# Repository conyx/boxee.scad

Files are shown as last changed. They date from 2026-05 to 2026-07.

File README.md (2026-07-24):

boxee.scad
==========

Parametric storage box with lid, created in [OpenSCAD](https://openscad.org/).
Everything is configured from the Customizer — no code editing needed.

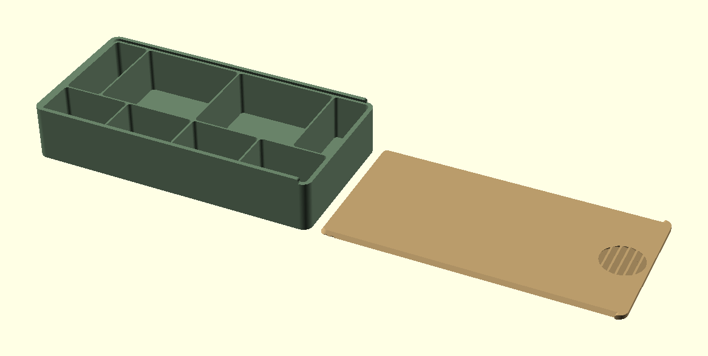
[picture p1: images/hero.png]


Main features
-------------

- [Compartment layout](#compartments) defined by a simple text string
- 10 [lid types](#lid-types) — friction lip, magnets, latches, hinges, slider
  and their combinations
- [Hinges](#hinges) joined by snap-fit (no hardware), pin, screw with nut or
  self-tapping screw
- [Snap locks](#snap-locks) holding the slider lid and latches closed
- [Magnet closure](#magnets--pausing-the-print) with print-pause support
- Corner [rounding](#rounding), [lid notches](#lid-notches),
  [connection bump/groove](#connection-groove--bump-mini-lip) (mini lip)
- [Dimension summary and hardware "shopping list"](#usage) (screws, pins,
  magnets)

Dependencies
------------

- **OpenSCAD — a recent [development snapshot (nightly)](https://openscad.org/downloads.html#snapshots) is recommended.**
  The 2021.01 stable release works too, but can be very slow with some specific
  parameters.
- **[BOSL2 library](https://github.com/BelfrySCAD/BOSL2)** — use the latest master;
  the hinges rely on recent BOSL2 features. Install it into your OpenSCAD library
  folder as described in the [BOSL2 installation guide](https://github.com/BelfrySCAD/BOSL2?tab=readme-ov-file#installation)
  (find the folder via *File ▸ Show Library Folder* in OpenSCAD).

Usage
-----

1. Open `main.scad` in OpenSCAD and show the Customizer (*Window ▸ Customizer*).
2. Define compartments and pick a lid type (see below). Every parameter has a
   description in the Customizer.
3. Preview (F5), render (F6), export STL. All parts are laid out side by side in
   print orientation.

The console (and a summary plate under the model in preview) reports the outside
dimensions, the hardware you need (screws, pins, magnets) and print-pause heights
for magnet closures.

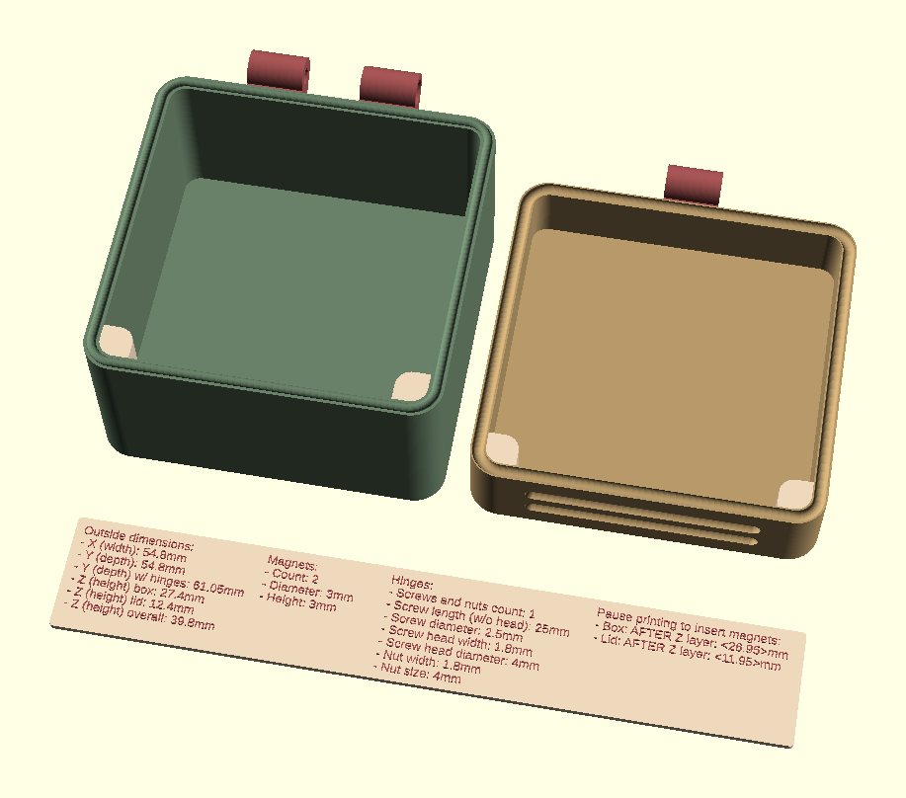
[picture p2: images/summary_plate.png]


Examples
--------

The [examples](examples) folder contains three ready-to-print projects, each
with the STL and photos of the printed result:

- **[Medi box](examples/medi_box)** — medical box with a slider lid and
  compartments sized for pill bottles; the cross-shaped notches on the lid make
  opening easier (the healthcare symbol visible on the walls in the photo is a
  negative volume added in the slicer software).
- **[Hardware box](examples/hardware_box)** — organizer for small screws and
  nuts, hinged together and lockable by a latch with snap lock. Needs two
  2.5 × 30 mm screws with nuts for the hinges.
- **[Tool box](examples/tool_box)** — box for iFixit tools with a lip and
  magnetic lid (the screwdriver pattern visible on the lid in the photo was
  added in the slicer software). Needs four 4 × 4 mm cylindrical magnets.

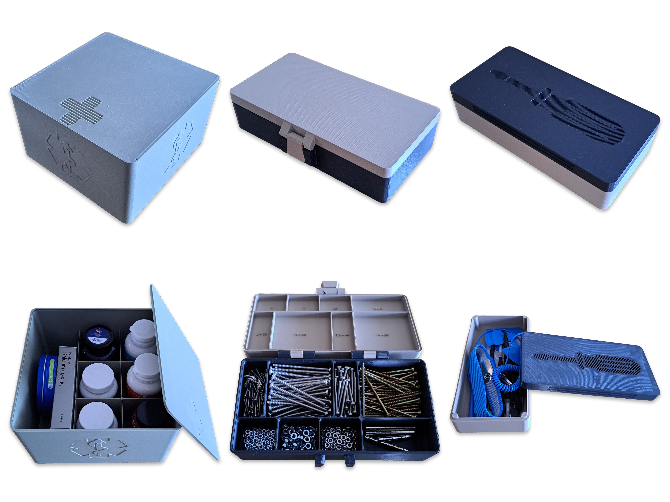
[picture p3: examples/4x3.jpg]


Compartments
------------

Compartments are defined by the text parameter `compartments_dimensions`.
Each row is `DEPTH, WIDTH, WIDTH, ...` — the first number is the row depth (Y),
followed by the widths (X) of its compartments. Rows are separated by `;`.
The box size is derived from the compartments plus wall/separator thickness —
`"50, 50"` gives a single 50×50 mm compartment.

`"50, 20, 55, 55, 20; 25, 37.5, 37.5, 37.5, 37.5"` — two rows: a 50 mm deep row
with four compartments and a 25 mm deep row with four equal ones.

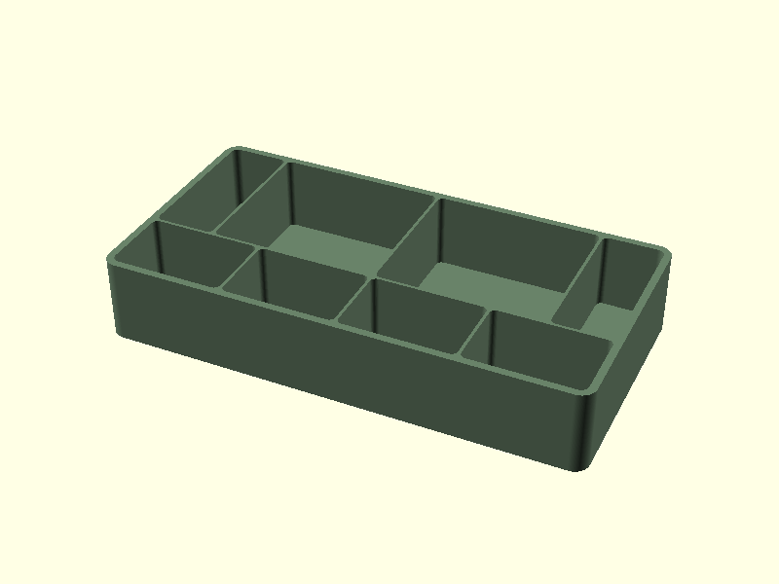
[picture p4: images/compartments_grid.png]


`compartments_transpose = true` — same definition, rows run along X instead of Y.

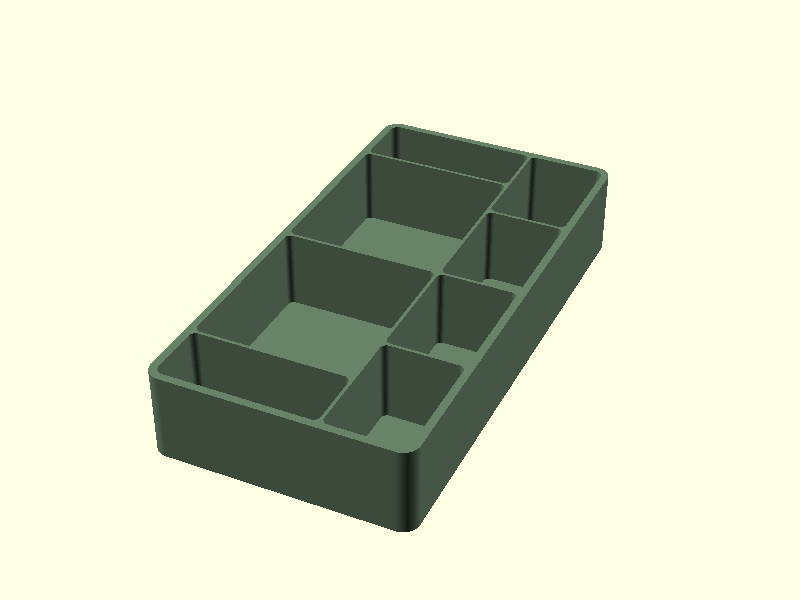
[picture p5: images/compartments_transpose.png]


`separators_z_offset = 15` — separators lowered from the top, leaving shared
space above the compartments.

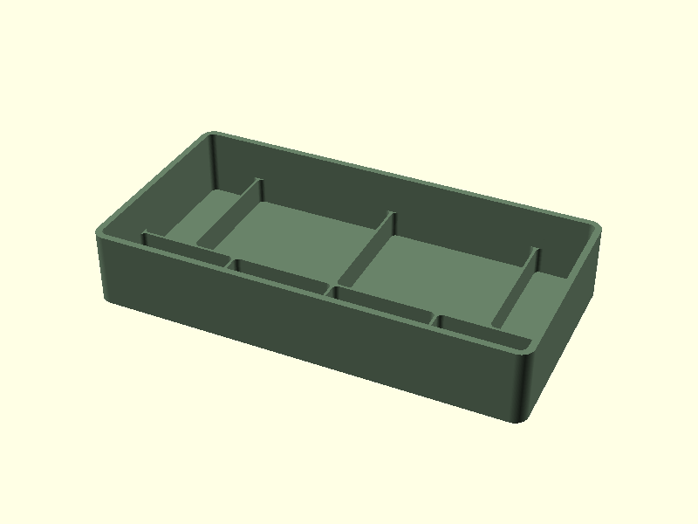
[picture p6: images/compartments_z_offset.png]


`separators_inside_lid = true` — matching separators are also generated inside
the lid (any lid type except slider).

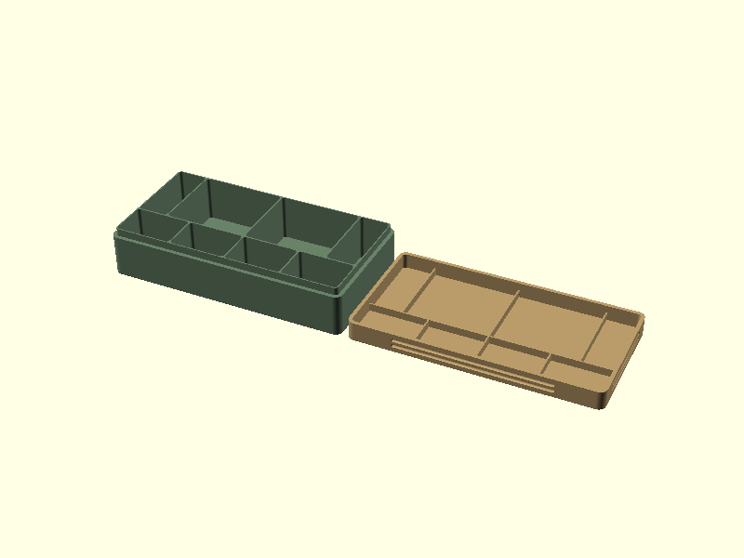
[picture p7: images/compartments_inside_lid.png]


Lid types
---------

Selected by `lid_type`. Box is always printed as one part; the lid (and latches)
are separate parts laid out next to it.

**No lid** (`no_lid`) — open tray.

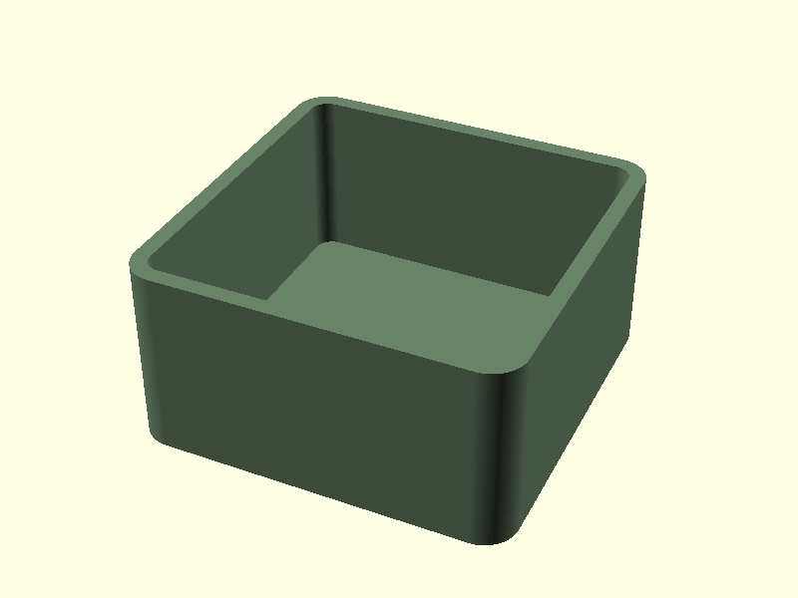
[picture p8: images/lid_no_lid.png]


**Lip** (`lip`) — inner lip on the box, the lid holds by friction. Tune the fit
with `lip_tolerance` (lower = tighter).

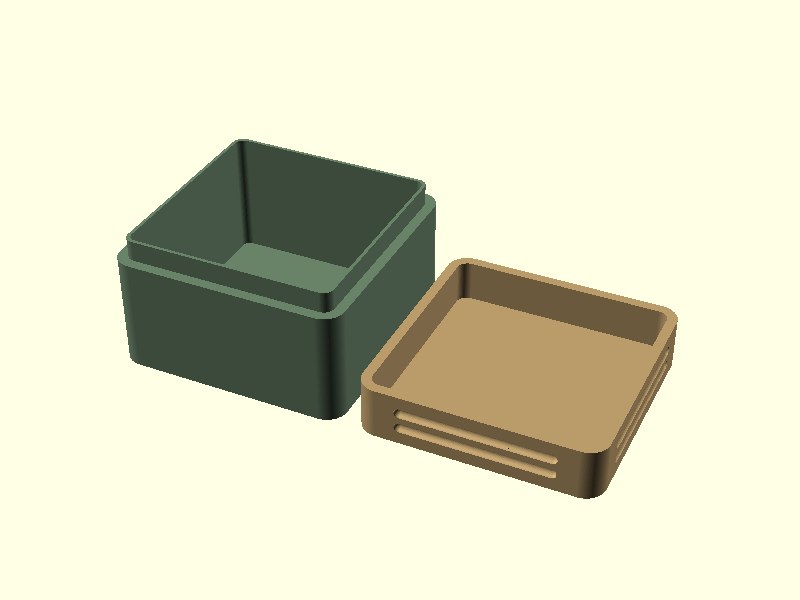
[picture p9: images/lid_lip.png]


**Magnets** (`magnets`) — flat mating faces with 2 or 4 magnet pairs in corner
holders. See [Magnets](#magnets--pausing-the-print).

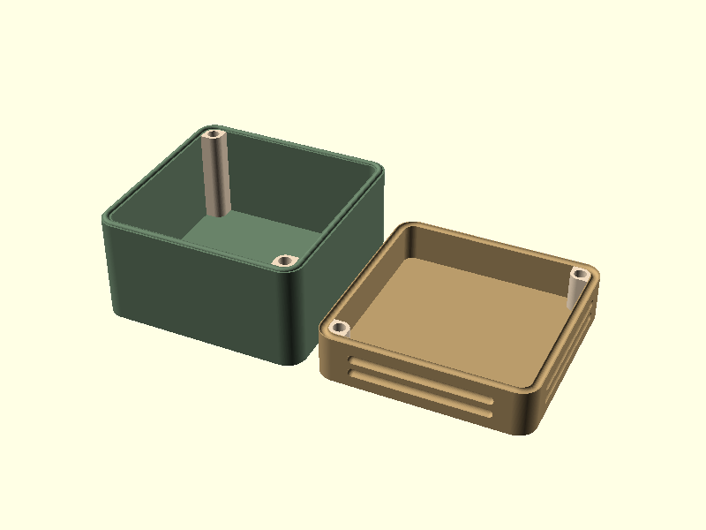
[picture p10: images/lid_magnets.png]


**Lip and magnets** (`lip_magnets`) — lip aligns the lid, magnets hold it closed.

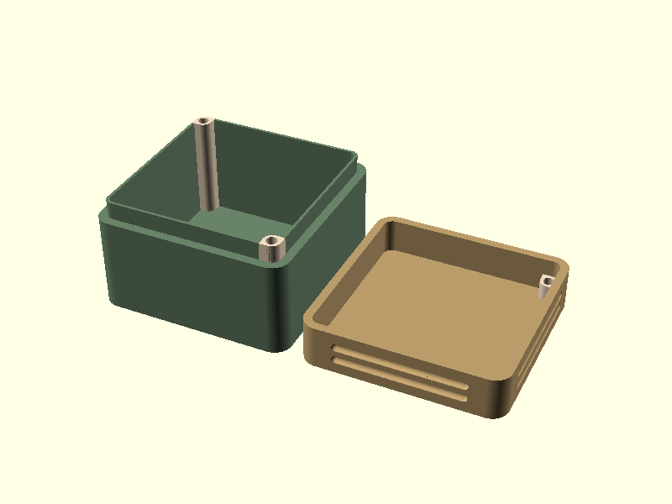
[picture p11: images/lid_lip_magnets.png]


**Latches** (`latches`) — dovetail latches on the front and back. The latch
swings on a snap-fit hinge and clicks onto the box.

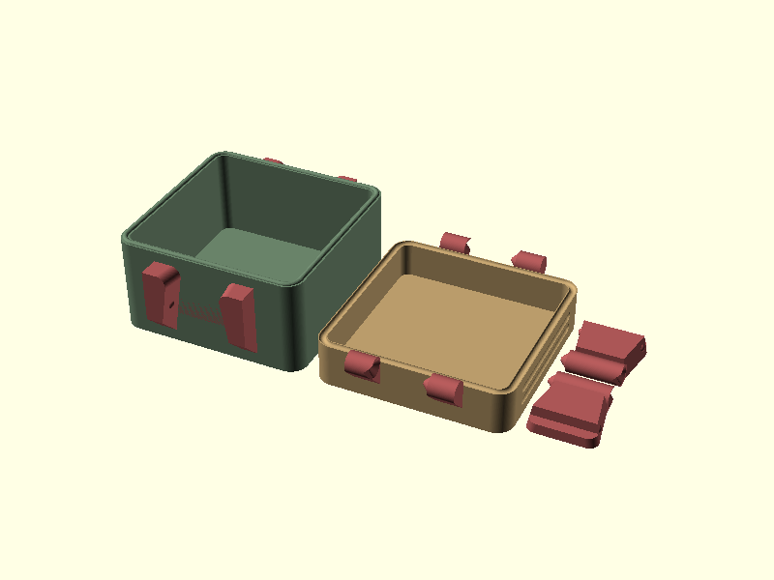
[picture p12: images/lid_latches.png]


**Lip and latches** (`lip_latches`) — friction lip plus latches.

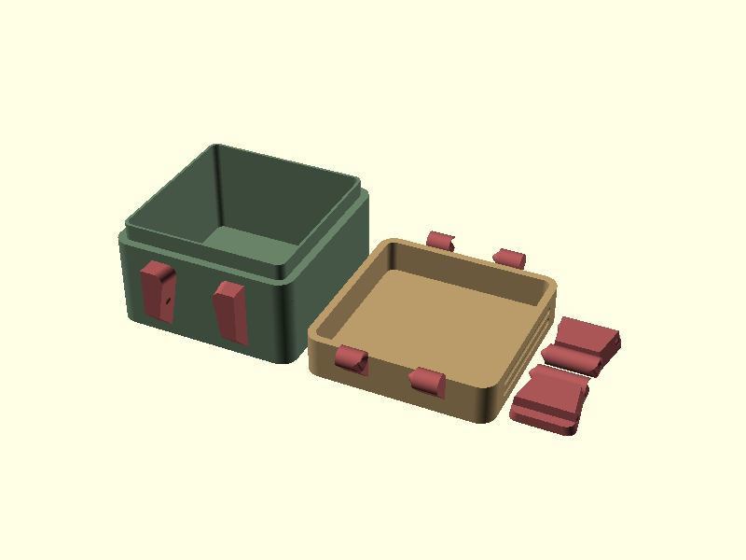
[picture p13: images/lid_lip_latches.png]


**Hinges** (`hinges`) — lid hinged at the back, nothing holds the front closed.

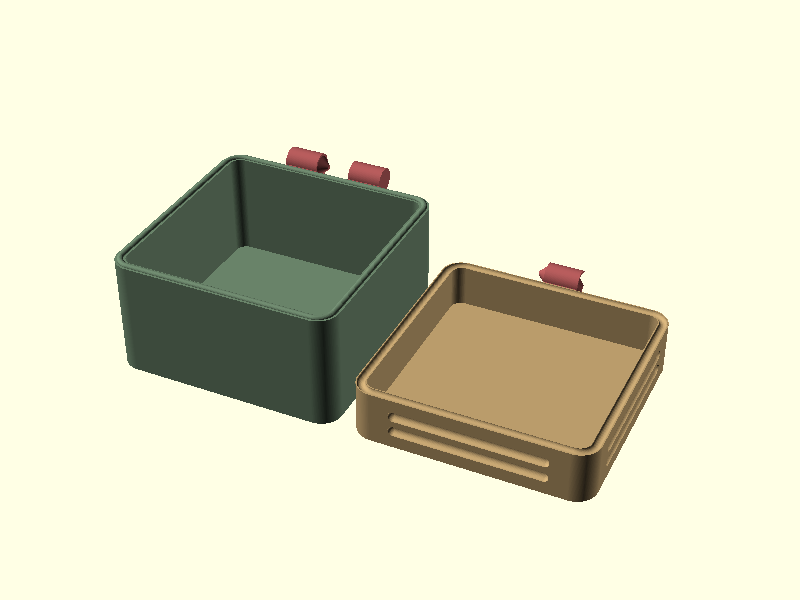
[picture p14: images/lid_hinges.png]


**Hinges and magnets** (`hinges_magnets`) — hinged lid held closed by magnets
(with 2 magnets both sit at the front edge).

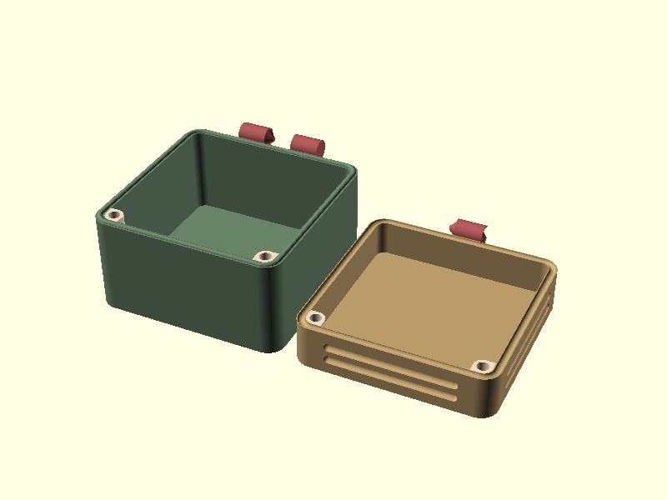
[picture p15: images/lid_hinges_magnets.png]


**Hinges and latches** (`hinges_latches`) — hinged lid with latches at the
front only.

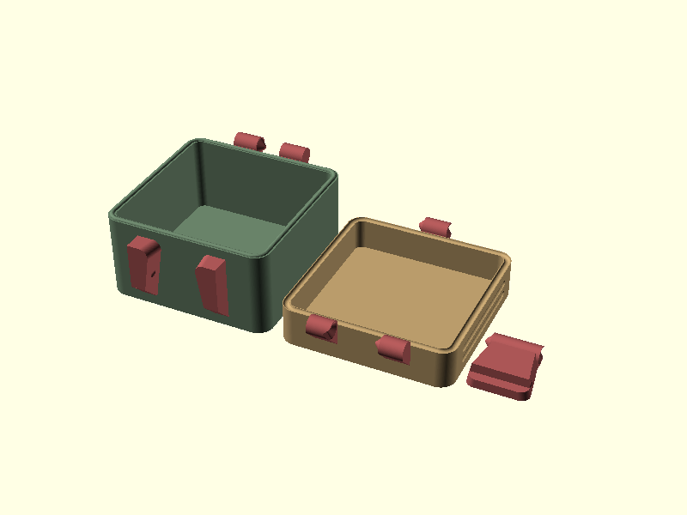
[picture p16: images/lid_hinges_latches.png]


**Slider** (`slider`) — flat lid slides into side rails, with optional snap lock
and a notch pattern for grip.

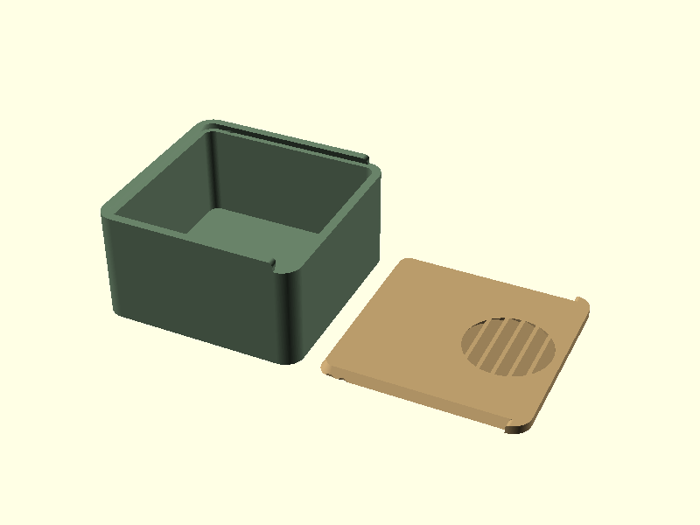
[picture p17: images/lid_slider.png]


Hinges
------

`hinge_join_type` selects how the hinge halves (one printed on the box, one on
the lid) are joined.

**Snap-fit** (`snap_fit`) — no hardware. Built-in cones on one half click into
sockets on the other; assembled by pressing together after printing. Needs ≥ 3
segments.

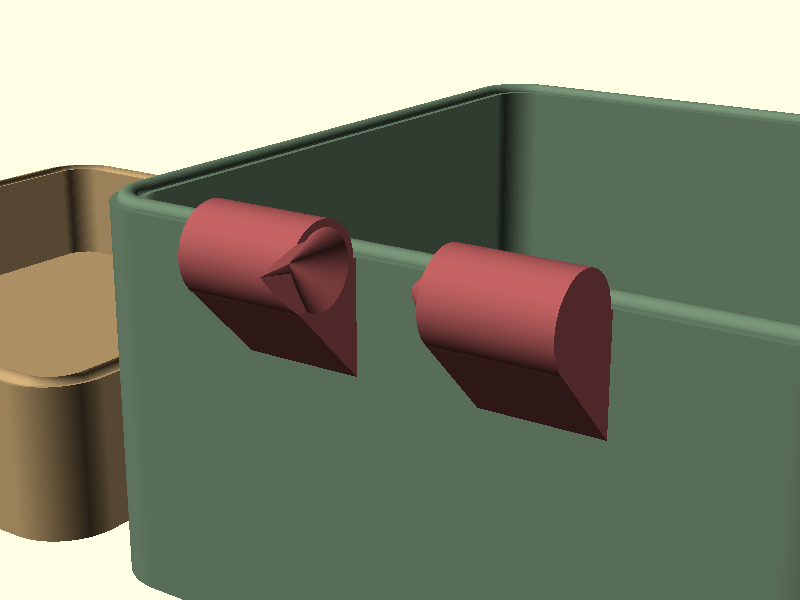
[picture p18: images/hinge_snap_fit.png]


**Simple pin** (`pin`) — plain hole through the knuckles. Use a nail, rod or a
piece of 1.75 mm filament as the pin.

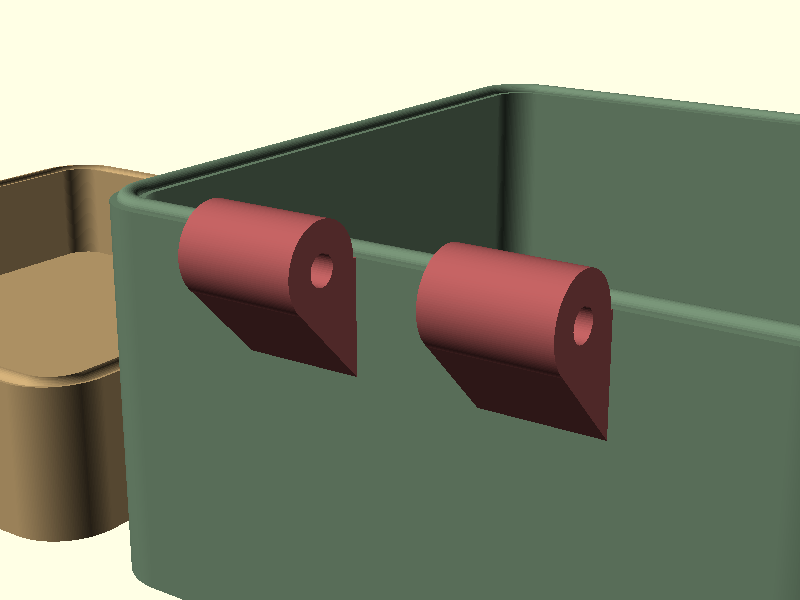
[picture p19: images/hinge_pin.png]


**Screw with nut** (`screw_nut`) — through hole with a counterbore for a flat
screw head on one end and a hex recess for the nut on the other.

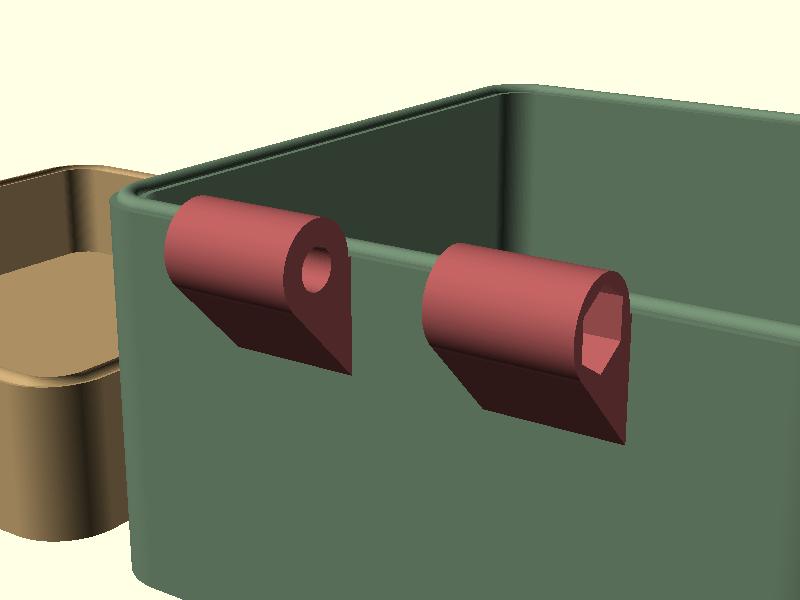
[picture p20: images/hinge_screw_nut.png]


**Self-tapping screw** (`screw_self_tap`) — countersink for the conical head;
the hole in the last segment is undersized so the screw taps into it.
ISO (M1.6–M6) and UTS (#0–#12) sizes.

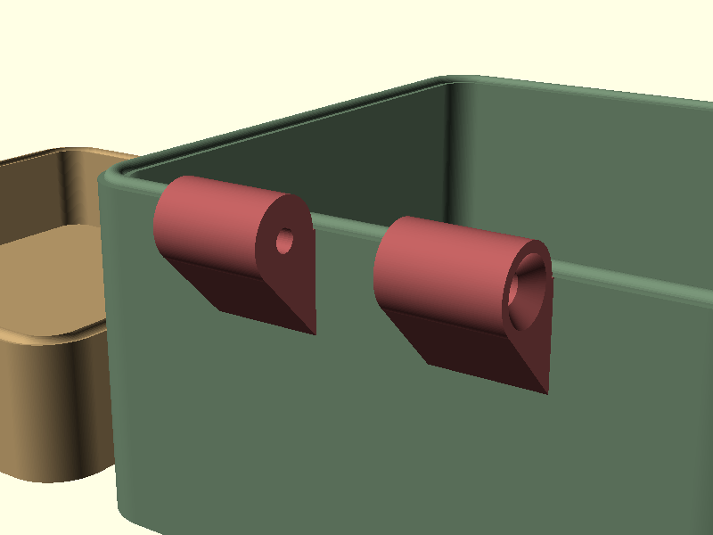
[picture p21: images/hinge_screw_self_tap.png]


Rounding
--------

`corner_outer_radius` and `corner_inner_radius` round the box/lid corners,
`compartment_bottom_radius` rounds the compartment floors (slow to render).

| Sharp (`0` / `0` / `0`) | Rounded (`10` / `20` / `10`) |
|---|---|
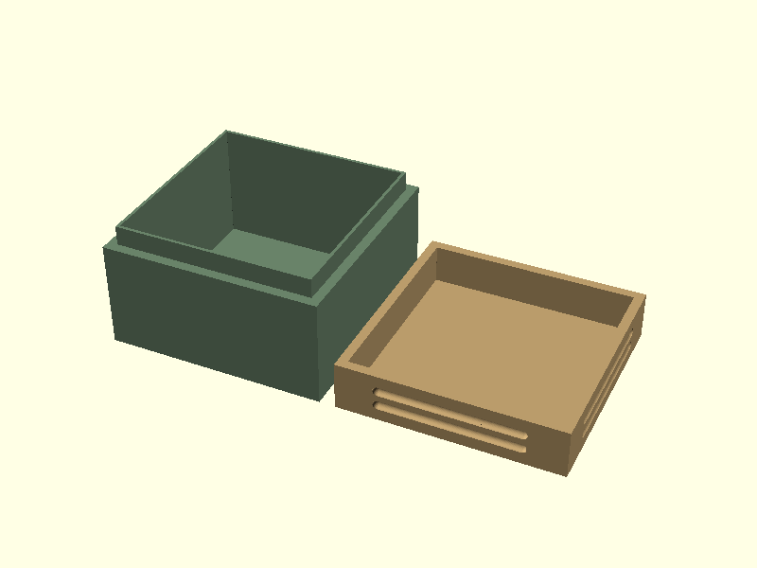
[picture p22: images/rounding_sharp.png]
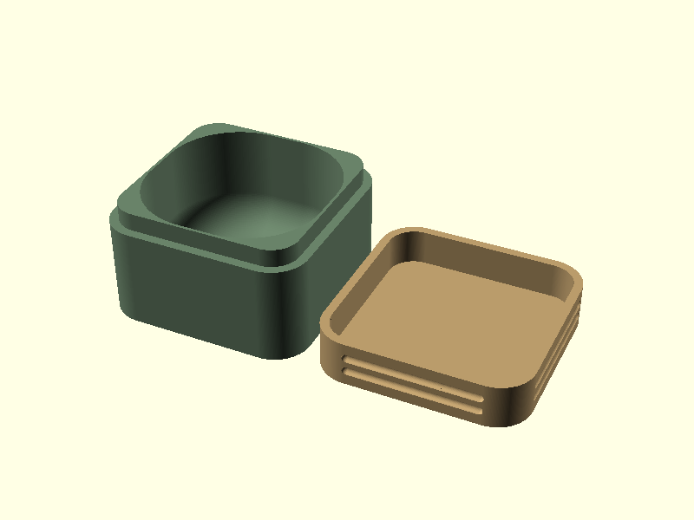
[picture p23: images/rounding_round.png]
|  |  |

Lid notches
-----------

Shallow finger grooves on the lid sides make the lid easier to grip and open.
Configure the sides (`lid_notches`: X / Y / both / none), the number of grooves
and their spacing. Sides carrying hinges or latches are skipped automatically.

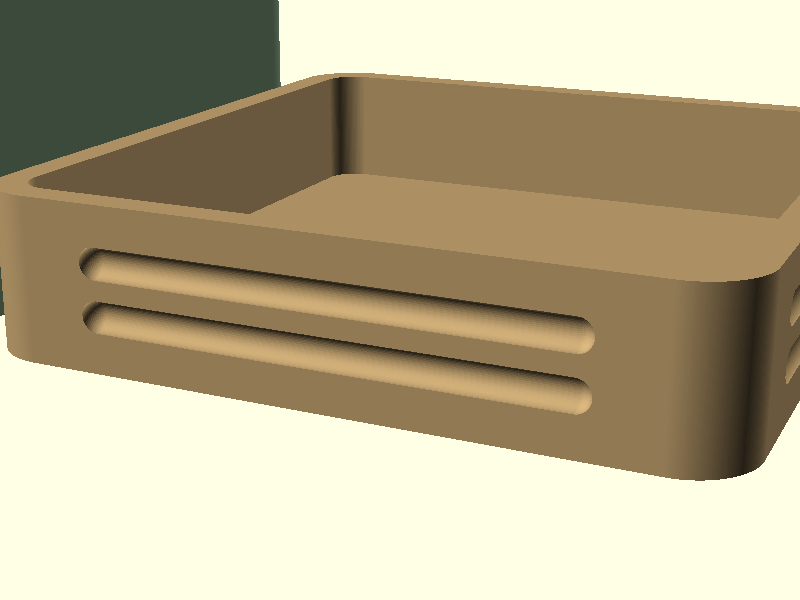
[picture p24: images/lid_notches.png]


Slider lid notches
------------------

The slider lid can carry a decorative grip pattern (`slider_lid_notches`):
full-width ribs or ribs clipped to a shape — circle, triangle, square, hexagon,
teardrop, cross or heart. Number, width, spacing, depth and position of the ribs
are configurable.

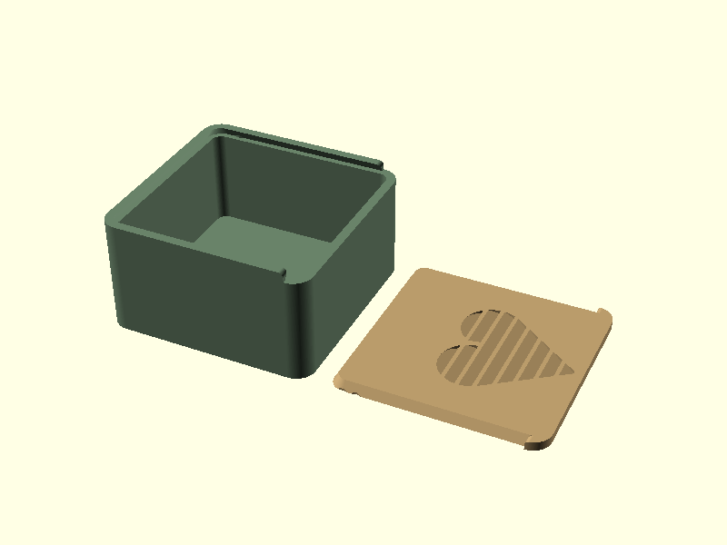
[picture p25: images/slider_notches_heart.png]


Connection groove / bump (mini lip)
-----------------------------------

For flat-faced lids (magnets, latches, hinges — without a lip), a small bump on
one rim can mate with a groove on the other. It aligns the lid and adds a light
hold. Choose which part gets the bump
(`connection_type`) and size both as a percentage of the wall thickness;
`connection_height_percentage` flattens the profile. Shown below with 4 mm
walls for visibility.

| Bump on the box rim | Groove around the lid rim |
|---|---|
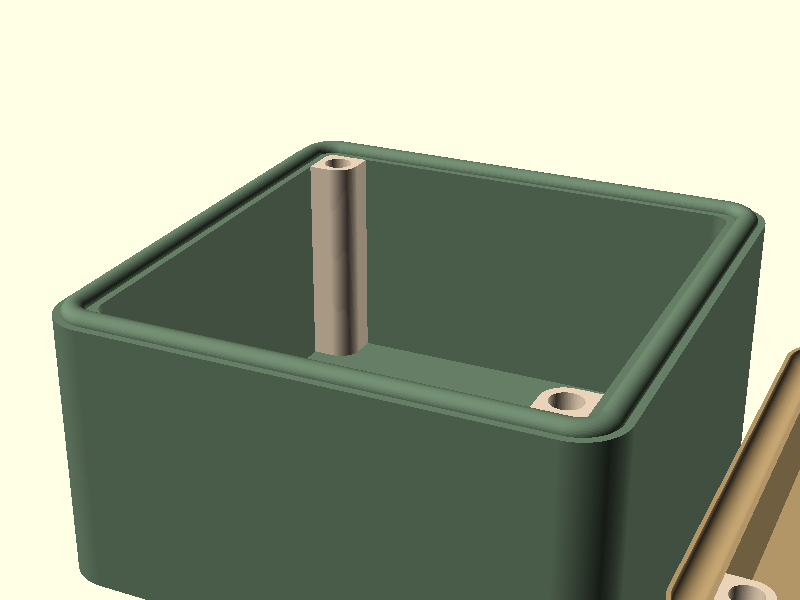
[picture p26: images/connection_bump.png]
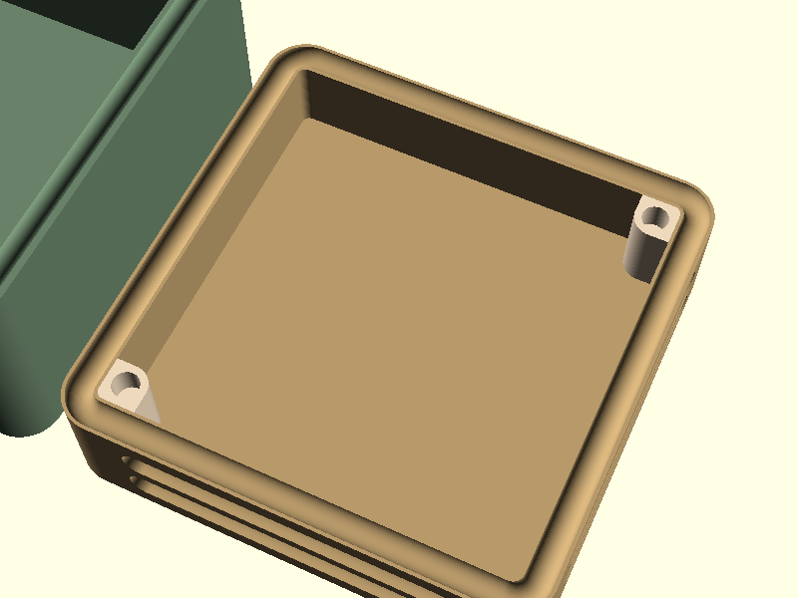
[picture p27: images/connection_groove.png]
|  |  |

Snap locks
----------

Both the slider lid and the latches can click shut:

- **Slider** — `slider_lid_snap_lock` adds small bumps at the ends of the box
  rails that snap into matching recesses in the lid, so the closed lid holds
  position with a click. `slider_lid_snap_lock_firmness` (0–1) scales the bumps.
- **Latches** — `latch_snap_lock` adds bumps that click into recesses in the
  latch seat on the box, keeping the latch closed. `latch_snap_lock_firmness`
  (0–1) scales them.

Both are tuned for the default tolerance of 0.1 mm — if you change
`slider_lid_tolerance` or `latch_tolerance`, you may need to adjust the
corresponding firmness.

Magnets & pausing the print
---------------------------

Magnet holders are printed into the corners of the box and lid. Holes are sized
from `magnet_diameter` / `magnet_height` plus `magnet_tolerance`, with
`magnet_glue_height` of extra depth for glue.

- **Default** (`magnet_generate_closure = false`): holes are open at the mating
  face — print normally, then glue the magnets in.
- **Closed holes** (`magnet_generate_closure = true`): a thin layer
  (`magnet_closure_height`) covers each hole, so the magnets must be inserted
  *during* the print. You have to **pause the print** at the right layer for both
  the box and the lid — the exact heights are echoed to the console and shown on
  the summary plate (e.g. `Box: AFTER Z layer: <26.95>mm`). In PrusaSlicer, add
  the pause with *Insert pause* at that layer — see
  [Prusa's guide](https://help.prusa3d.com/article/insert-pause-or-custom-g-code-at-layer_120490).

Double-check magnet polarity before inserting: every box/lid pair must attract.

Other features
--------------

- Every fit has its own tolerance parameter — lip, slider, magnets, latches,
  hinge pin and screw hardware.
- The interior height is split between box and lid by `bottom_height` /
  `lid_height`; wall thickness (`thickness`) and separator thickness
  (`separator_thickness`) are independent.
- Hinges: count, segment count and length ratio, knuckle diameter and arm angle
  are configurable; `hinge_flip_last` mirrors the last hinge for easier
  screwdriver access or a symmetric pair.
- Latches: count, size and the angles of the support and hinge arm are
  configurable.
- `model_detail_preview` / `model_detail_render` trade speed for smoothness
  separately in preview and in the final render.

License
-------

[CC BY-SA 4.0](LICENSE.txt)

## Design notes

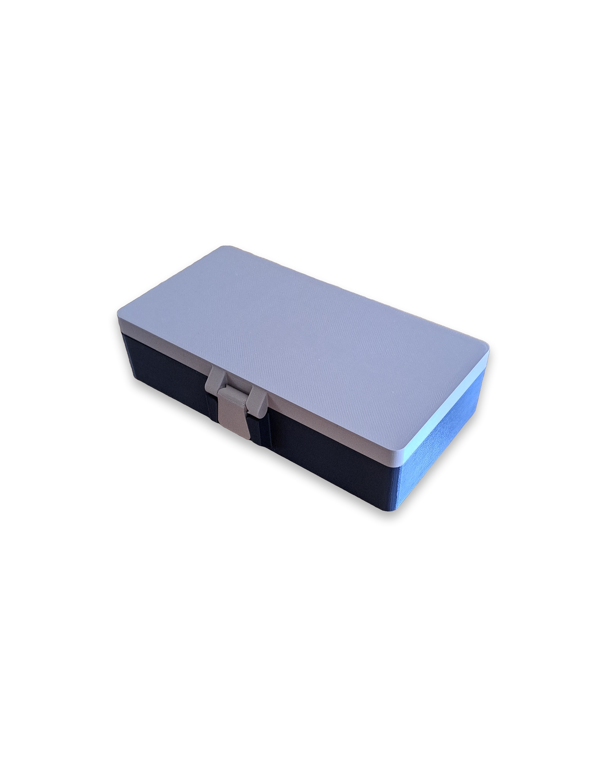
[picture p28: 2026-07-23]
examples/hardware_box/hardware_box_01.jpg

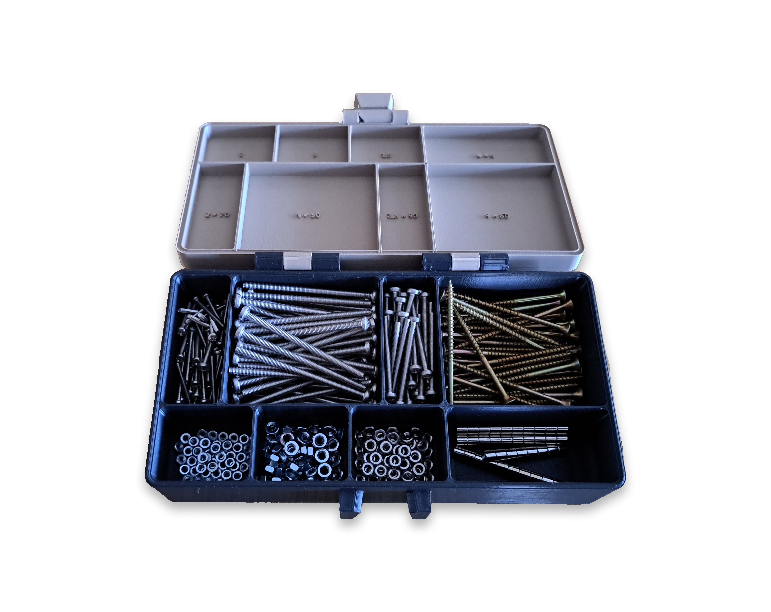
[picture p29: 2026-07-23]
examples/hardware_box/hardware_box_02.jpg

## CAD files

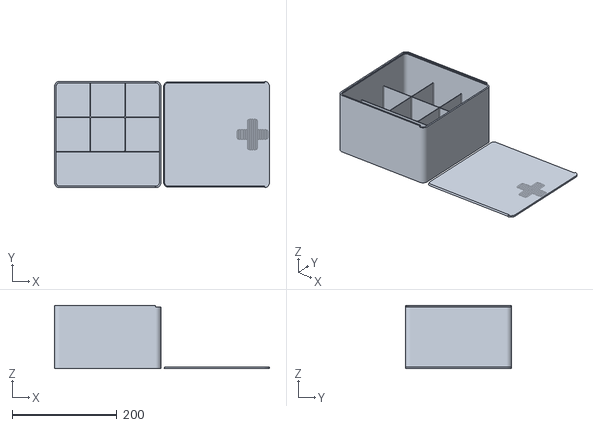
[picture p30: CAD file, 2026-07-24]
examples/medi_box/medi_box.stl
410.0 x 203.0 x 121.0

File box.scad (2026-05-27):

// Main box module
module box() {
  color(BOX_COLOR)
  difference() {
    union() {
      left(get_generate_lid() ? get_x_width_outside()/2 + get_box_x_margin() : 0)
      difference() {
        union() {
          // Outer body
          up(get_bottom_height_outside()/2)
            cuboid([get_x_width_outside(), get_y_depth_outside(), get_bottom_height_outside()],
                   rounding = corner_outer_radius,
                   edges = "Z");

          // Inner body that forms lip
          up(get_box_height_outside()/2)
            cuboid([get_x_width_outside() - thickness*2 - get_lp_tolerance()*2,
                    get_y_depth_outside() - thickness*2 - get_lp_tolerance()*2,
                    get_box_height_outside()],
                   rounding = get_lip_rounding(),
                   edges = "Z");
        }

        compartment_outer_rounding = max(
          MIN_CORNER_RADIUS,
          corner_inner_radius,
          corner_outer_radius - thickness - get_lp_thickness() - get_lp_tolerance()
        );

        // Cut out inside
        compartments(
          height = get_box_height_outside(),
          z_offset = thickness,
          outer_rounding = compartment_outer_rounding,
          inner_rounding = max(MIN_CORNER_RADIUS, corner_inner_radius),
          bottom_rounding = compartment_bottom_radius,
          edge_extension = 0
        );

        // Cut out separator Z offset from the top
        if (separators_z_offset > 0) {
          assert(separators_z_offset <= bottom_height + get_lp_height(),
            str("separators_z_offset must be less than bottom_height (+ lip_height if lip used) (= ",
                bottom_height + get_lp_height(), "mm). ",
                "Current value: ", separators_z_offset, "mm"));

          up(get_box_height_outside() - separators_z_offset)
            cuboid([get_x_width(), get_y_depth(), separators_z_offset + SWO],
                   rounding = compartment_outer_rounding,
                   edges = "Z",
                   anchor = BOTTOM);
        }
      }

      if (lid_type == "slider") {
        // Rail which holds slider lid
        slider_rail_box();
      }

      // Connection bump
      connection_box("bump");
    }

    // Cut out magnet holders space
    magnet_holders_box(clearance = true);

    // Cut out connection groove
    connection_box("groove");
  }
}

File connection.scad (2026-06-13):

// Connection bump / groove modules
// Bump is the smaller protrusion, groove is the larger channel that receives it.

module connection_sweep(diameter) {
  scale([1, 1, get_connection_height_scale()])
    path_sweep2d(
      circle(d = diameter),
      rect([get_x_width_outside() - thickness, get_y_depth_outside() - thickness],
          rounding = get_connection_rounding()),
      closed=true
    );
}

// type = "bump" or "groove"
module connection_box(type) {
  if (get_generate_connection()) {
    assert(connection_groove_percentage >= connection_bump_percentage,
      str("connection_groove_percentage must be greater than or equal to connection_bump_percentage. ",
          "Groove: ", connection_groove_percentage, "%, Bump: ", connection_bump_percentage, "%"));
  }

  should_render = get_generate_connection() && (
    (type == "bump" && connection_type == "bump_box") ||
    (type == "groove" && connection_type == "bump_lid")
  );

  if (should_render) {
    left(get_generate_lid() ? get_x_width_outside()/2 + get_box_x_margin() : 0)
    up(get_bottom_height_outside())
      connection_sweep(type == "bump" ? get_connection_bump_diameter() : get_connection_groove_diameter());
  }
}

// type = "bump" or "groove"
module connection_lid(type) {
  should_render = get_generate_connection() && (
    (type == "bump" && connection_type == "bump_lid") ||
    (type == "groove" && connection_type == "bump_box")
  );

  if (should_render) {
    move([get_x_width_outside()/2 + get_lid_x_margin(), 0, get_lid_height_outside()])
      connection_sweep(
        type == "bump"
          ? get_connection_bump_diameter()
          : get_connection_groove_diameter()
      );
  }
}

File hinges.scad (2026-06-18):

module knuckle_hinge_wrapper(length,
                             segs,
                             offset,
                             inner,
                             arm_angle,
                             gap,
                             seg_ratio,
                             knuckle_diam,
                             pin_diam,
                             snap_fit,
                             snap_fit_firmness,
                             tap_depth) {
  difference() {
    knuckle_hinge(length = length,
                  segs = segs,
                  offset = offset,
                  inner = inner,
                  arm_angle = arm_angle,
                  gap = gap,
                  seg_ratio = seg_ratio,
                  knuckle_diam = knuckle_diam,
                  pin_diam = pin_diam,
                  clear_top = true,
                  in_place = snap_fit,
                  tap_depth = tap_depth,
                  screw_head = "flat");
    if (snap_fit) {
      knuckle_hinge_snap_fit_sockets(length = length,
                                     segs = segs,
                                     offset = offset,
                                     inner = inner,
                                     gap = gap,
                                     seg_ratio = seg_ratio,
                                     knuckle_diam = knuckle_diam,
                                     pin_diam = pin_diam,
                                     firmness = snap_fit_firmness);
    }
  }
}

// Snap-fit sockets: per segment, a channel from the pin axis up to the barrel
// top (a hull of two pin-coaxial 45-degree cones) that the mating cone presses
// into radially and is gripped by. `firmness` shrinks the cone 0.35..0.55 mm
// (smaller = firmer). Layout mirrors knuckle_hinge() so each socket lands where
// a mating cone seats.
module knuckle_hinge_snap_fit_sockets(length,
                                      segs,
                                      offset,
                                      inner,
                                      gap,
                                      seg_ratio,
                                      knuckle_diam,
                                      pin_diam,
                                      firmness) {
  // segment layout, mirroring knuckle_hinge()
  outer_segments_number = ceil(segs / 2);
  inner_segments_number = floor(segs / 2);
  outer_segment_length  = gap
                          + (length - (segs - 1) * gap)
                          / (outer_segments_number + inner_segments_number * seg_ratio);
  inner_segment_length  = gap
                          + (length - (segs - 1) * gap)
                          / (outer_segments_number + inner_segments_number * seg_ratio)
                          * seg_ratio;
  segments_number       = inner ? inner_segments_number : outer_segments_number;
  segment_spacing       = outer_segment_length + inner_segment_length;
  // even counts shift half a segment to stay centred
  even_segments_x_shift = segs % 2 == 1 ? 0
                        : inner ? outer_segment_length / 2
                        : inner_segment_length / 2;
  segment_body_length   = (inner ? inner_segment_length : outer_segment_length) - gap;

  // socket cone = mating cone (base radius pin_diam/2, 45 degrees) shrunk by
  // firmness so it grips the male cone (smaller = firmer)
  shrink      = lerp(0.35, 0.55, firmness);
  cone_radius = pin_diam / 2 - shrink;
  cone_height = pin_diam / 2 * tan(45) - shrink;
  assert(cone_radius > 0 && cone_height > 0,
         "snap-fit socket collapsed: pin_diam too small for this firmness");

  // BOSL2 cuts the in_place cone's spike at 80% of its height (flat tip = 20% of
  // the base radius). Match that on the seat cone so the mating cone's flat tip
  // seats firmly instead of jamming on a sharp apex.
  spike_keep      = 0.8;
  seat_height     = cone_height * spike_keep;
  seat_tip_radius = cone_radius * (1 - spike_keep);

  // the socket opens on the +X face (outer) / -X face (inner) of each segment
  socket_face_x_offset = (inner ? -1 : 1) * (segment_body_length / 2 + SWO);
  pin_z        = offset;
  barrel_top_z = offset + knuckle_diam / 2;

  // knuckle_hinge() runs segments along -X by index, so step copies likewise
  left(even_segments_x_shift)
    xcopies(n = segments_number, spacing = -segment_spacing) {
      // the hinge's far end has no mating cone, so it needs no socket
      is_edge = (!inner && segs % 2 == 1 && $idx == 0) ||
                (inner && segs % 2 == 0 && $idx == segments_number - 1);
      if (!is_edge) {
        // a spike-cut seat on the pin axis, hulled up to a full lead-in cone
        // at the barrel top: the channel the mating cone presses down into
        hull()
          for (c = [[pin_z,        seat_height, seat_tip_radius],  // seat (spike-cut)
                    [barrel_top_z, cone_height, 0]])               // lead-in (full cone)
            let (z = c[0], cone_len = c[1], tip_radius = c[2])
              // base on the receiving face, tip pointing into the segment
              translate([socket_face_x_offset, 0, z])
                xcyl(l = cone_len,
                     r1 = inner ? cone_radius : tip_radius,
                     r2 = inner ? tip_radius : cone_radius,
                     anchor = inner ? LEFT : RIGHT);
      }
    }
}

module hinge(is_box_hinge) {
  screw_head_cut_h = hinge_screw_head_width + 2 * hinge_screw_nut_tolerance;
  screw_head_cut_d = hinge_screw_head_diameter + 2 * hinge_screw_nut_tolerance;
  screw_nut_cut_h = 1.5 * hinge_nut_width + 2 * hinge_screw_nut_tolerance;
  screw_nut_cut_id = hinge_nut_size + 2 * hinge_screw_nut_tolerance;

  color(OUTSIDE_ACCESSORIES_COLOR)
  difference() {
    xrot(-90) zrot(180)
      knuckle_hinge_wrapper(
        length = get_hinge_length(),
        segs = hinge_segments,
        offset = get_hinge_knuckle_offset(),
        knuckle_diam = hinge_knuckle_diameter,
        pin_diam = get_hinge_hole_diameter(),
        tap_depth = hinge_self_tap_screw_tap_depth,
        snap_fit = hinge_join_type == "snap_fit",
        snap_fit_firmness = hinge_snap_fit_firmness,
        gap = hinge_segments_gap,
        inner = !is_box_hinge,
        arm_angle = hinge_arm_angle,
        seg_ratio = hinge_segments_ratio,
        $slop = hinge_join_type == "pin" ? hinge_pin_tolerance
              : hinge_join_type == "screw_nut" ? hinge_screw_nut_tolerance
              : 0
      );

    // Screw head/nut hole in first segment
    if (hinge_join_type == "screw_nut") {
      x_offset = get_hinge_length()/2 - screw_head_cut_h/2 + SWO/2;
      y_offset = hinge_knuckle_diameter/2 + hinge_mount_gap;
      odd_segments = hinge_segments % 2 == 1;

        if (xor(!is_box_hinge, odd_segments)) {
          move([x_offset * (is_box_hinge ? -1 : 1), y_offset, 0])
            regular_prism(
              6,
              h = screw_nut_cut_h + SWO,
              id = screw_nut_cut_id,
              orient = RIGHT
            );
        }

        if (is_box_hinge) {
          move([x_offset, y_offset, 0])
          xcyl(h = screw_head_cut_h + SWO,
               d = screw_head_cut_d);
        }
    }
  }
}

module hinges() {
  // Hinge-related assertions (only when hinges are used)
  if (get_generate_hinges()) {
    assert(hinges_number * get_hinge_length() <= get_x_width_outside(),
           str("Total hinge length exceeds box width. ",
               "Total hinge length: ", hinges_number * get_hinge_length(), "mm, ",
               "box width: ", get_x_width_outside(), "mm"));

    if (hinge_join_type == "snap_fit") {
      assert(hinge_segments >= 3,
             str("Snap-fit hinge requires at least 3 segments. ",
                 "Current segments: ", hinge_segments));
    }

    if (hinge_join_type == "screw_nut") {
      screw_head_cut_diameter = hinge_screw_head_diameter + 2*hinge_screw_nut_tolerance;
      screw_nut_cut_diameter = (hinge_nut_size + 2*hinge_screw_nut_tolerance) / cos(30);

      assert(hinge_knuckle_diameter >= screw_head_cut_diameter,
             str("hinge_knuckle_diameter is too small for screw head. ",
                 "Knuckle diameter: ", hinge_knuckle_diameter, "mm, ",
                 "screw head diameter (with tolerance): ", screw_head_cut_diameter, "mm"));

      assert(hinge_knuckle_diameter >= screw_nut_cut_diameter,
             str("hinge_knuckle_diameter is too small for screw nut. ",
                 "Knuckle diameter: ", hinge_knuckle_diameter, "mm, ",
                 "nut outer diameter (with tolerance): ", screw_nut_cut_diameter, "mm"));
    }
  }

  if (get_generate_hinges()) {
    // Calculate spacing for equal distribution along X axis
    hinge_spacing = (get_x_width_outside() - hinges_number * get_hinge_length()) / (hinges_number + 1);

    box_center_x = -(get_x_width_outside()/2 + get_box_x_margin());
    lid_center_x = get_x_width_outside()/2 + get_lid_x_margin();
    hinge_y = get_y_depth_outside()/2;
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

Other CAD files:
latches.scad
main.scad
utils.scad

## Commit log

2026-05-13 hinge_hardware_tolerance & $slop
    [hinges.scad, main.scad, utils.scad]
2026-05-20 Adjust customizer variables descriptions
    [main.scad]
2026-05-27 Add .editorconfig
    [box.scad, latches.scad, main.scad]
2026-06-04 snap fit hinges
    [hinges.scad]
2026-06-07 Adjust snap_fit_firmness
    [hinges.scad]
2026-06-11 Fix $slop of self-tap screw hinge
    [hinges.scad, main.scad, utils.scad]
2026-06-12 change hinge_mount_gap default value 0.25
    [main.scad]
2026-06-12 connection_bump_percentage adjust default value
    [main.scad]
2026-06-13 Adjust default customizer values
    [main.scad]
2026-06-15 $preview variable init issue workaround
    [main.scad]
2026-06-18 nut counterbore is hinge_nut_width multiply by 1.5
    [hinges.scad, main.scad]
2026-06-18 Improve customizer
    [main.scad]
2026-06-25 Improve customizer variable description
    [main.scad]
2026-07-03 Change customizer variables ordering
    [main.scad]
2026-07-23 model_detail_stl -> model_detail_render
    [main.scad, utils.scad]
2026-07-24 Update README and upload example STL files
    [medi_box.stl]
2026-08-12 make pack command: boxee.zip for Thingverse & Printables
2026-11-03 Report box height incl. slider rail in summary
